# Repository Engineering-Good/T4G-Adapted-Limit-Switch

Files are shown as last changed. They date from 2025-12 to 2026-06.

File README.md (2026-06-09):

# Adapted Limit Switch
<!--- TITLE --->
<!--- Open Source Assistive Technology: GitHub Readme Template --->
<!--- SUMMARY --->
The Adapted Limit Switch is a cost effective, open source assistive switch similar to commercially available Wobble Switches. The switch is activated by applying force to and moving a wand in any direction. The switch can be activated by various body parts including the limbs and head. It provides a momentary closed contact that can be used to activate various assistive devices. The Adapted Limit Switch has an interchangeable topper that can be swapped for different shapes and sizes and the base can install with different type of camera mount or clamp . The switch requires approximately 0.55 N (55 gf) and about 24 mm of travel to operate, though this will vary a bit depending on the topper attached.

The current version of the device (v1.0) has been built and user tested.

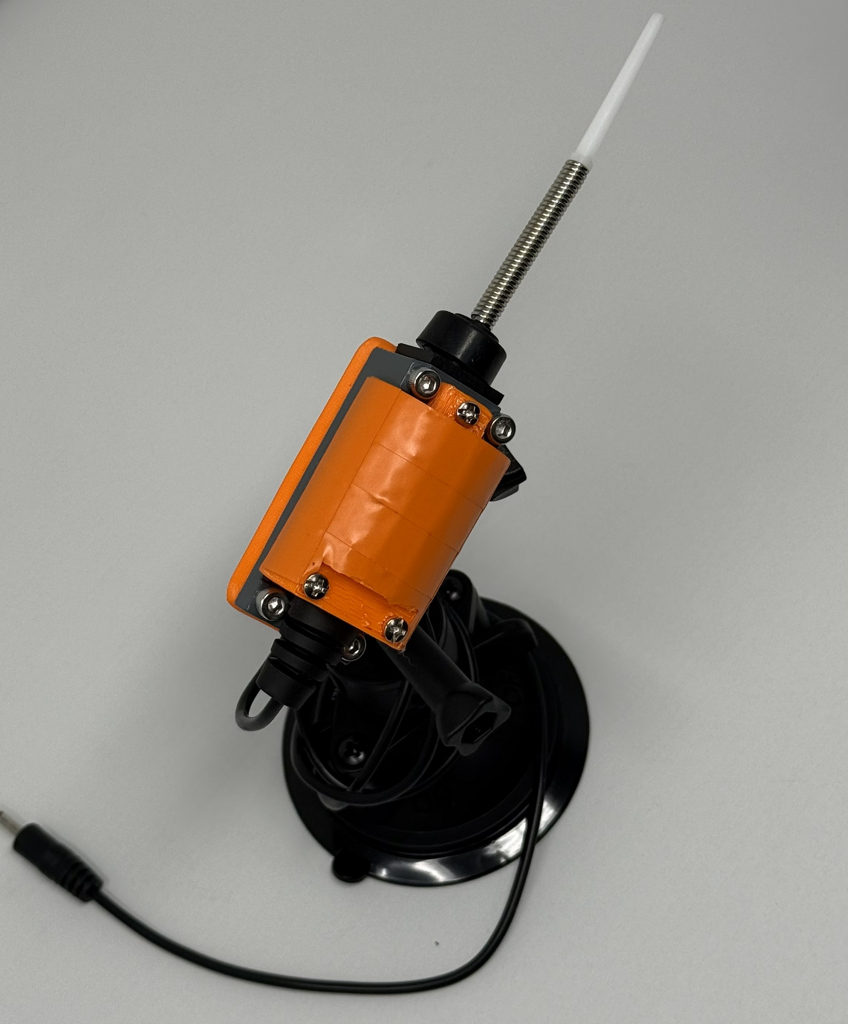
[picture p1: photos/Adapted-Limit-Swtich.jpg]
Picture of Adapted Limit Swtich


## How to Obtain the Device

### 1. Do-it-Yourself (DIY) or Do-it-Together (DIT)

This is an open-source assistive technology, so anyone is free to build it. All of the files and instructions required to build the device are contained within this repository. Refer to the Maker Guide below.

### 2. Get Involved: Requests & Volunteering

- Need this device? If you or someone you know could benefit from the Adapted Limit Switch, please send us an email at [contactus@engineeringgood.org](mailto:contactus@engineeringgood.org). We also invite you to share your journey with us! Tell us your stories about the device and feedback help us make our assistive tech even better!

- Want to help? We are always looking for volunteers to help build these devices for the community. If you have the skills and want to contribute, please contact us via email at [contactus@engineeringgood.org](mailto:contactus@engineeringgood.org).

## Build Instructions

### 1. Read through the Maker Guide

The [Maker Guide](/documentation/Product_Manual_Adapted_Limit_Switch.pdf)  contains all the necessary information to build this device, including tool lists, assembly instructions, and testing.

### 2. Order the Off-The-Shelf Components

The [Bill of Materials](/documentation/Adapted_Limit_Switch_BOM.csv) lists all of the parts and components required to build the Adapted Limit Switch.

### 3. Assemble the Adapted Limit Switch

Reference the Assembly Guide section of the [Maker Guide](/documentation/Product_Manual_Adapted_Limit_Switch.pdf) for the tools and steps required to build each portion.

## How to improve this Device

As open source assistive technology, you are welcomed and encouraged to improve upon the design.

## Files

### Documentation

| Document | Version | Link |
|---|---|---|
| Maker Guide | 1.0 | [Adapted_Limit_Switch_Maker_Guide](/documentation/Product_Manual_Adapted_Limit_Switch.pdf) |
| Bill of Materials | 1.0 | [Adapted_Limit_Switch_Bill_of_Materials](/documentation/Adapted_Limit_Switch_BOM.csv) |
| User Guide | 1.0 | [Adapted_Limit_Switch_User_Guide](/documentation/Product_Manual_Adapted_Limit_Switch.pdf) |
| Changelog | 1.0 | [Adapted_Limit_Switch_Change_Log](/documentation/CHANGES.txt) |

## Open Hardware Attribution

The core design for this Adapted Limit Switch is based on the Open Wobble Switch, an open-source assistive technology project.
- Original Designer: Makers Making Change (a program of Neil Squire).
- Original Copyright:  Copyright (c) Neil Squire / Makers Making Change.
- Original Source Location: The original project source files are available online at [Open Wobble Switch](https://www.makersmakingchange.com/product/open-wobble-switch/01tJR000000698oYAA0)

## License

Copyright (c) 2024 Engineering Good.

This repository describes Open Hardware:

- Everything needed or used to design, make, test, or prepare the Adapted Limit Switch is licensed under the [CERN 2.0 Weakly Reciprocal license (CERN-OHL-W v2) or later](https://cern.ch/cern-ohl).
- All software is under the [GNU General Public License v3.0 (GPL-3.0)](https://www.gnu.org/licenses/gpl.html).
- Accompanying material such as instruction manuals, videos, and other copyrightable works that are useful but not necessary to design, make, test, or prepare the Adapted Limit Switch are published under a [Creative Commons Attribution-ShareAlike 4.0 license (CC BY-SA 4.0)](https://creativecommons.org/licenses/by-sa/4.0/).

You may redistribute and modify this documentation and make products using it under the terms of the [CERN-OHL-W v2](https://cern.ch/cern-ohl).
This documentation is distributed WITHOUT ANY EXPRESS OR IMPLIED WARRANTY, INCLUDING OF MERCHANTABILITY, SATISFACTORY QUALITY AND FITNESS FOR A PARTICULAR PURPOSE.
Please see the CERN-OHL-W v2 for applicable conditions.

Source Location: <https://github.com/makersmakingchange/Open-Wobble-Switch>

----

<!-- ABOUT EG START -->
## About Engineering Good

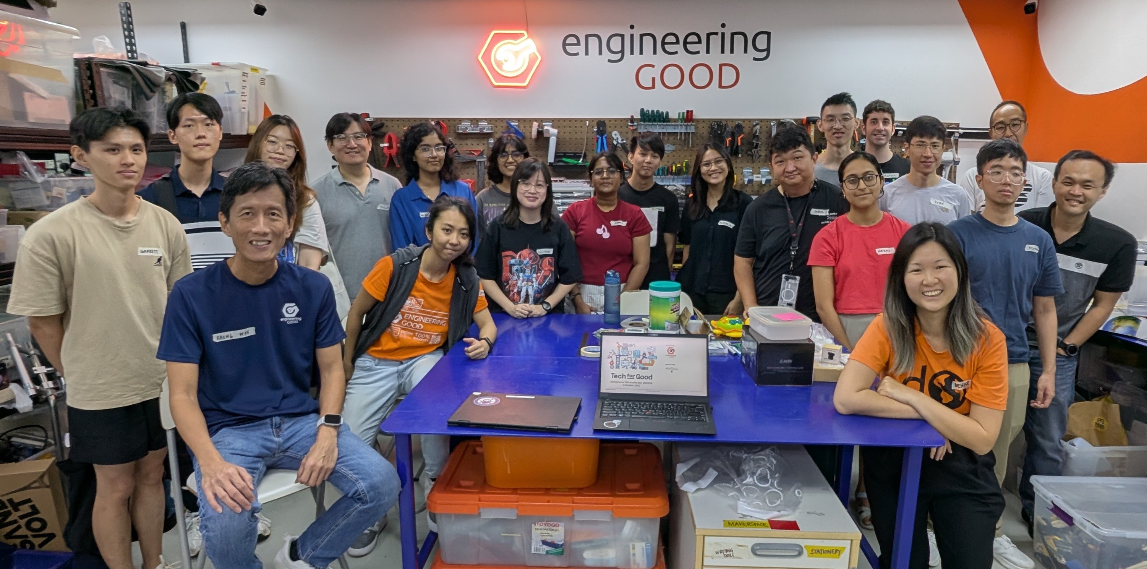
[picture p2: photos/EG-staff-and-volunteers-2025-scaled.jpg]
Picture of EG staff and volunteers.


- Website: [https://www.engineeringgood.org](https://www.engineeringgood.org)
- GitHub: [Engineering Good](https://github.com/Engineering-Good)
- Instagram: [@engineeringgood](https://www.instagram.com/engineeringgood/)
- Facebook: [engineeringgood](https://www.facebook.com/engineeringgood.org/)
- LinkedIn: [engineeringgood](https://www.linkedin.com/company/engineeringgood/?originalSubdomain=sg)
- Thingiverse: [engineeringgood](https://www.thingiverse.com/engineeringgood/designs)
- Printables: [@engineeringg_4351657](https://www.printables.com/@engineeringg_4351657)

### Contact Us

For technical or non-techical questions, to get involved, or to share your experience we encourage you to 
- Visit [our website](https://www.engineeringgood.org/)
- Vontact us via [contact us form](https://www.engineeringgood.org/contact-faq/)
- Email us at [contactus@engineeringgood.org](mailto:contactus@engineeringgood.org)
- Volunteering Opportunities [working in progress](https://www.notion.so/engineeringgood/Volunteering-Opportunities-2025-ffa3d3ec8bb34ac7a672f5c10ee8177b)
<!-- ABOUT EG END -->

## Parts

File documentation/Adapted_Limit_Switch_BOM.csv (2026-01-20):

Item | Product Link | Supplier | Price | Quantity
3D printed top part | https://www.polymate.tech/3d-printing-orders | Polymate | 3.00 SGD/pcs | 1
3D printed bottom part | https://www.polymate.tech/3d-printing-orders | Polymate | 3.00 SGD/pcs | 1
Limit switch | https://amzn.asia/d/4A6GOT8 | Amazon | 22.08 SGD | 1
3.5mm male mono audio jack cable | https://sg.shp.ee/Wysp8yu | Shopee | 5.42 SGD/10pcs | 1
M3 x 20mm partially threaded screw | https://sg.shp.ee/Db9QmNu | Shopee | 6.16 SGD/3pcs | 2
M3 x 6mm screw | https://sg.shp.ee/EN4TQR4 | Shopee | 1.80 SGD/pcs | 1
M4 x 16mm bolt | https://sg.shp.ee/2jGwF62 | Shopee | 1.67 SGD/5pcs | 2
M4 x 30mm bolt | https://sg.shp.ee/zS49WkP | Shopee | 1.90 SGD/5pcs | 2
M4 nut | https://sg.shp.ee/pazvoqT | Shopee | 1.87 SGD/20pcs | 4
M5 Tee nut 1/4"-20 | https://amzn.asia/d/fEdIprT | Amazon | 24.50 SGD/100pcs | 1
Bicycle soft handle grip | https://shop.daisosingapore.com.sg/products/4550480051574 | Daiso | 2.18 SGD/2pcs | 1
Soft ball | https://sg.shp.ee/dVmJJah | Shopee | 0.73 SGD/pcs | 1

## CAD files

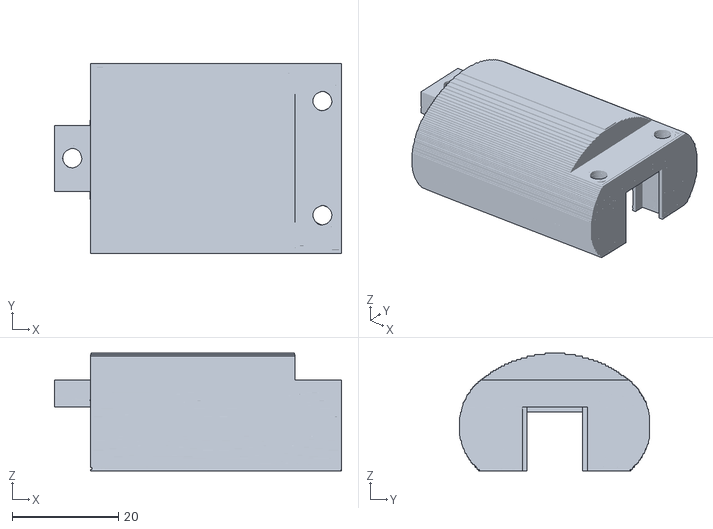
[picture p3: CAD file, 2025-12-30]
design-files/cad-files/Top_Piece.stl
54.1 x 35.9 x 22.2

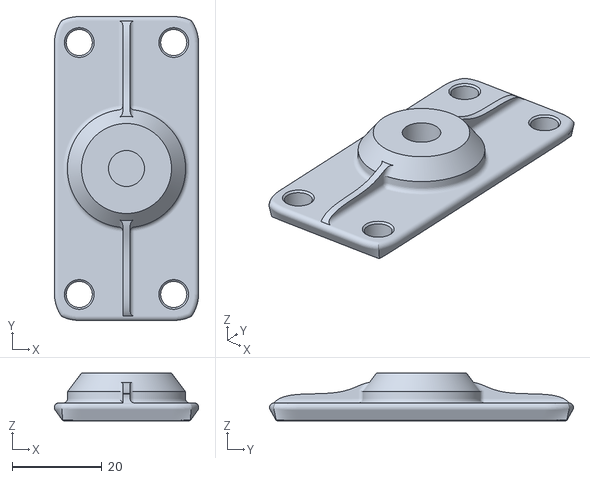
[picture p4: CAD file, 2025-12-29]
design-files/cad-files/Bottom_Piece.stl
32.1 x 67.6 x 10.7

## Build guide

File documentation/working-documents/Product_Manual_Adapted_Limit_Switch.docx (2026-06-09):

# Product Manual: Adapted Limit Switch

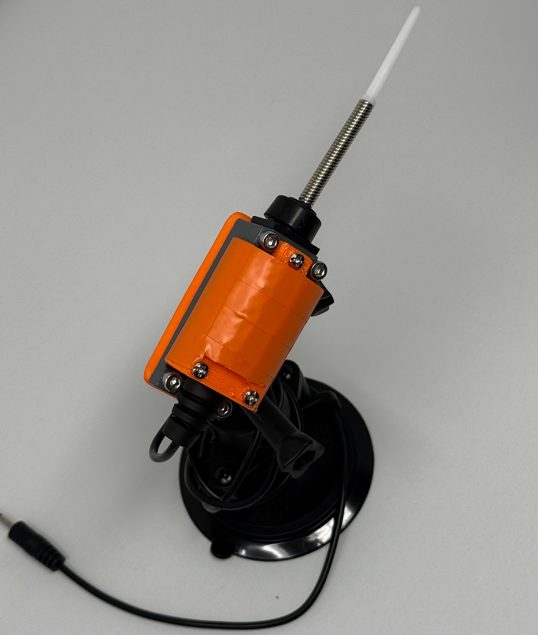
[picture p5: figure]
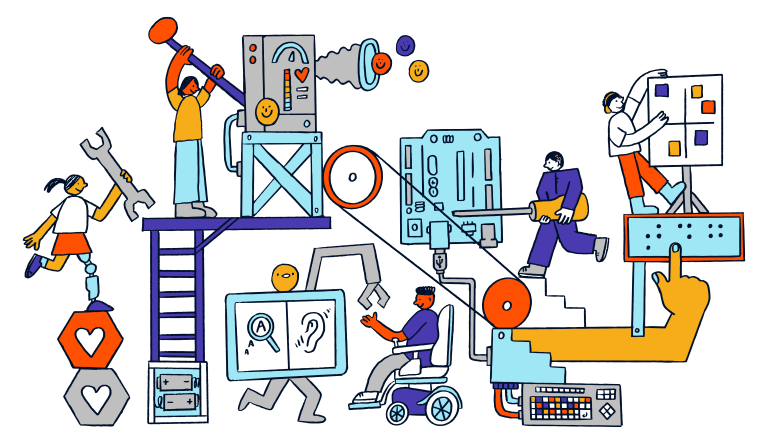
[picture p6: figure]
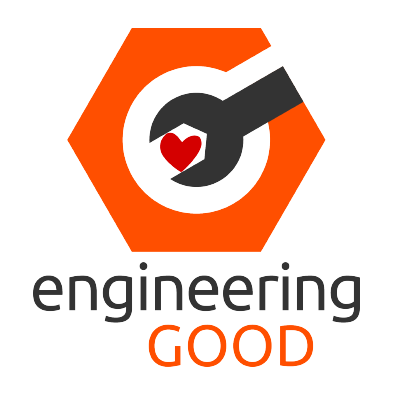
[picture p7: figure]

Revision: 1.0

Date: 03-Dec-2025

# Table of Contents

Table of Contents 1

1. Introduction 2

1.1 About the Community Partner 2

1.2 Product Description 3

WHY? 3

WHO? 3

WHAT? 3

HOW? 3

1.3 Product Overview and Features 4

1.4 Bill of Materials (BOM) 5

2. User Guide: Instructions for Use 6

2.1 Set Up Instructions 7

2.2 Maintenance 10

2.3 Troubleshooting 10

3. Maker Guide: Assembly Instructions 11

3.1 Assembly Guide 12

4. Credit and Open Hardware Licence 15

4.1. Open Hardware Attribution 15

4.2. License Statement and Source Availability 16

4.3 CERN Open Hardware Licence 16

# 1. Introduction

## 1.1 About the Community Partner

Our journey began in 1970 with the will of Mrs Shakuntala Bhatia. Under the banner of the Asian Women’s Welfare Association, Mrs Bhatia and her peers, like Mrs Tambyah and Mrs Kula, identified gaps in the community to help the underserved.

The Association incorporated AWWA Ltd on 7 January 2015, a Singapore company limited by guarantee. In April of the same year, AWWA Ltd took over the operations and activities previously managed by the Association. In 2022, the Association was dissolved, and AWWA continues to address social service gaps as they arise, by being guided by our mission and strategic vision.

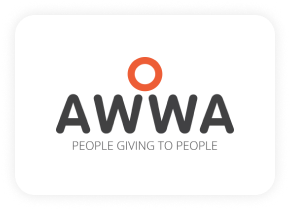
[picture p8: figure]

## 1.2 Product Description

This table clarifies the intended purpose and scope of the product:

WHY? | Special needs students with low mobility are often excluded from using toys and/or face lack of appropriate ways to express themselves.
WHO? | For special needs students with low mobility who are learning to understand cause-and-effect and have fun.
WHAT? | A limit switch with an additional 3.5mm male mono audio cable to trigger the power of other toys or play back audio. 3D printed casing with camera mounting hole for easy install clamp and mount on the wheelchair
HOW? | This product transforms an off-the-shelf limit switch into a durable and responsive device that triggers power on/off other toys or playback audio and an easy mounting mechanism . It allows students to use the limit switches to experience and understand the cause-and-effect.

## 1.3 Product Overview and Features

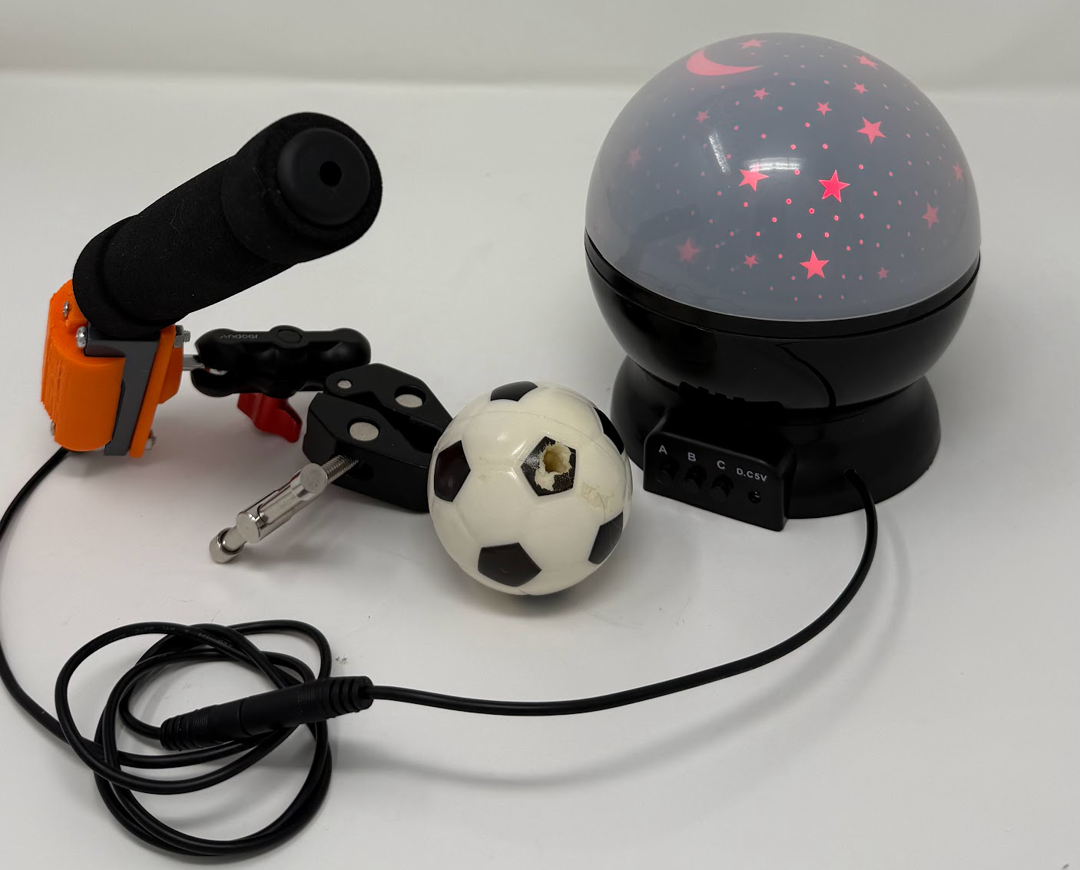
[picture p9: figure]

1. Adapted Limit Switch support push in all directions to trigger. Left, right, up or down it can be triggered.
2. Add-on soft ball, soft bicycle handle or soft toy to trigger stick to make it more interesting to students to try it out.
3. Can support different types of mounting or clamp system with standardised camera mount.
4. Connect to other electronic toys with a female 3.5mm mono audio jack cable.

## 1.4 Bill of Materials (BOM)

Item | Product Link | Supplier | Price | Quantity
3D printed top part | https://www.polymate.tech/3d-printing-orders | Polymate | 3.00 SGD/pcs | 1
3D printed bottom part | https://www.polymate.tech/3d-printing-orders | Polymate | 3.00 SGD/pcs | 1
Limit switch | https://amzn.asia/d/4A6GOT8 | Amazon | 22.08 SGD | 1
3.5mm male mono audio jack cable | https://sg.shp.ee/Wysp8yu | Shopee | 5.42 SGD/10pcs | 1
M3 x 20mm partially threaded screw | https://sg.shp.ee/Db9QmNu | Shopee | 6.16 SGD/3pcs | 2
M3 x 6mm screw | https://sg.shp.ee/EN4TQR4 | Shopee | 1.80 SGD/pcs | 1
M4 x 16mm bolt | https://sg.shp.ee/2jGwF62 | Shopee | 1.67 SGD/5pcs | 2
M4 x 30mm bolt | https://sg.shp.ee/zS49WkP | Shopee | 1.90 SGD/5pcs | 2
M4 nut | https://sg.shp.ee/pazvoqT | Shopee | 1.87 SGD/20pcs | 4
M5 Tee nut 1/4"-20 | https://amzn.asia/d/fEdIprT | Amazon | 24.50 SGD/100pcs | 1
Bicycle soft handle grip | https://shop.daisosingapore.com.sg/products/4550480051574 | Daiso | 2.18 SGD/2pcs | 1
Soft ball | https://sg.shp.ee/dVmJJah | Shopee | 0.73 SGD/pcs | 1

# 2. User Guide: Instructions for Use

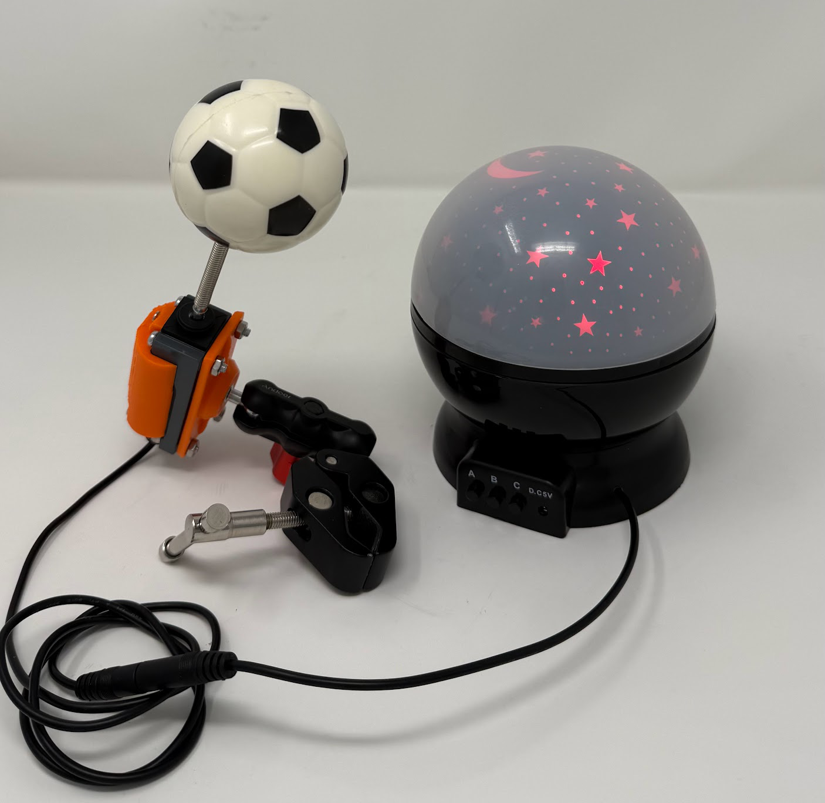
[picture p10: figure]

## 2.1 Set Up Instructions

Use the following table for a step-by-step guide to setting up the product:

Setting up

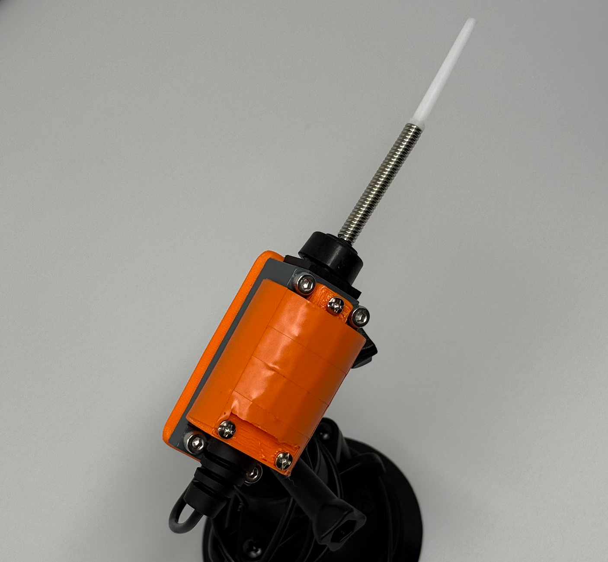
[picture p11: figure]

Push the white or spring to the left or right to trigger it.

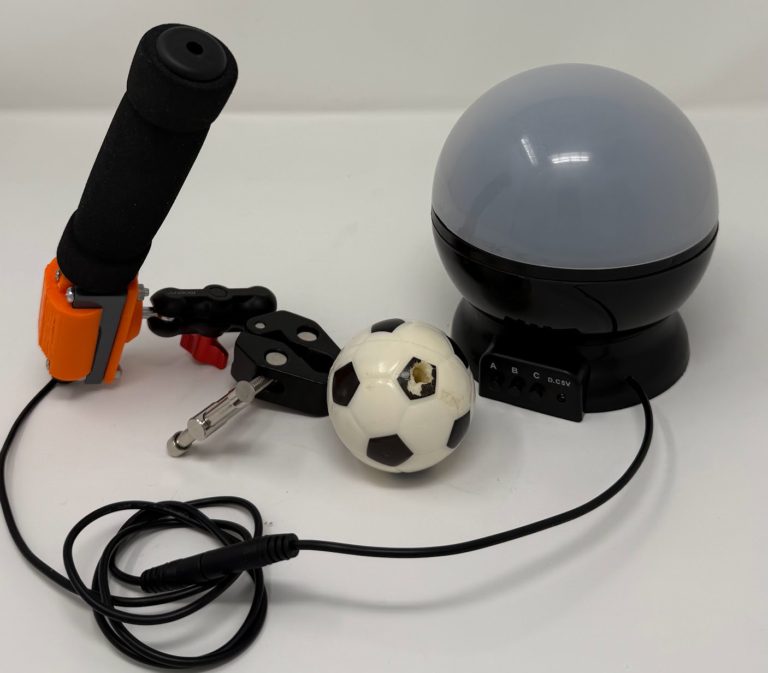
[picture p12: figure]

Connect the 3.5mm male mono audio jack cable to toys

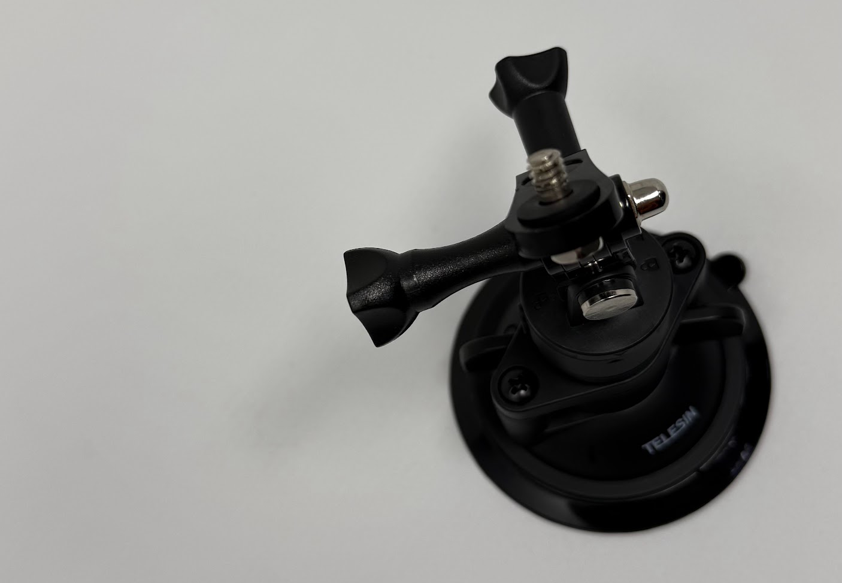
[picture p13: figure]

Suction cup mount. Secure the device properly by pushing the locking lever at the bottom side of the mount. It should be used on a flat surface.

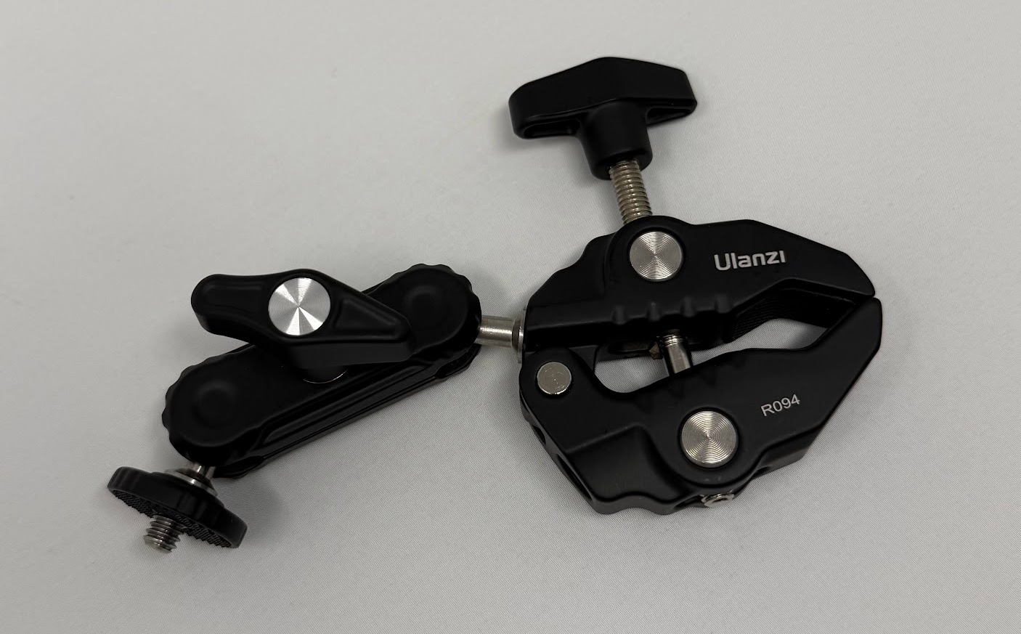
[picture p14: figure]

Clamp mount. Secure the device properly by turning the big knob and change the angle with the small knob on the mount. It is mostly used on a wheelchair.

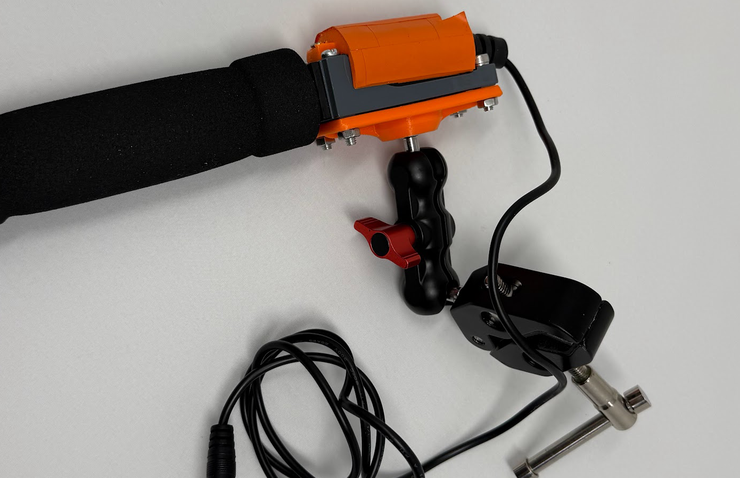
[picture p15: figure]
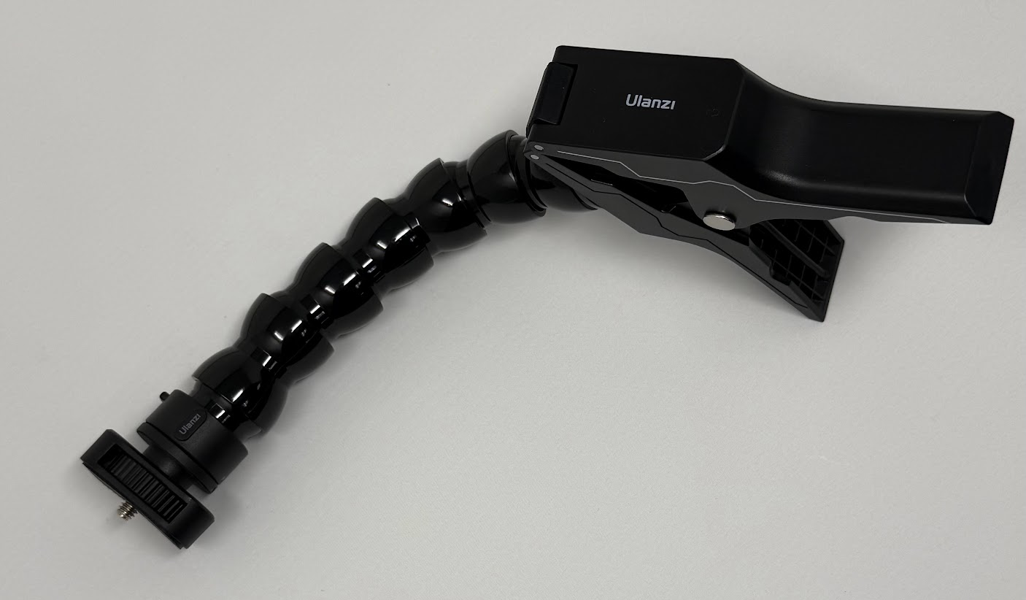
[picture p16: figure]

Gooseneck mount. Secure the device properly by squeezing the clip part and the gooseneck can adjust the angle. It is mostly used on a wheelchair.

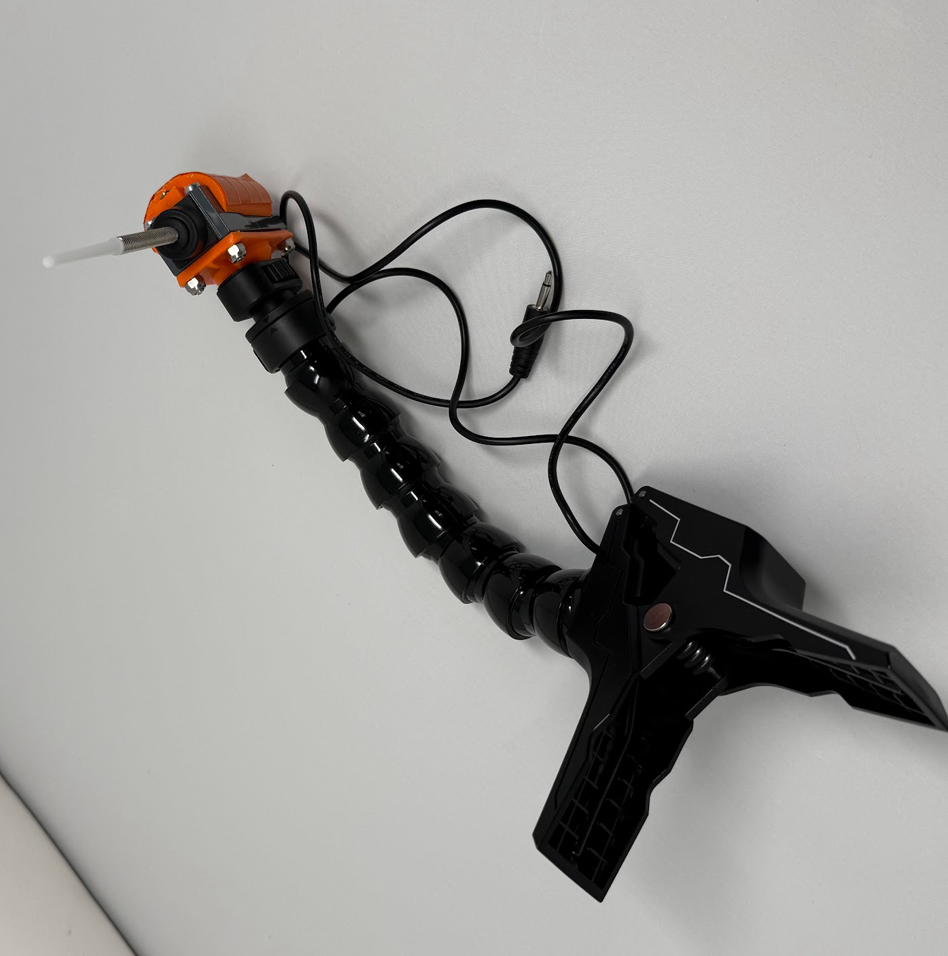
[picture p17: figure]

## 2.2 Maintenance

1. Check the clamp mounting if it is loose.
2. Check the 3.5mm male mono audio jack cable if it is loose or damaged.

## 2.3 Troubleshooting

Problem | Possible Cause | What You Can Try
The clamp or mount is loose so didn’t trigger toy | Didn’t clamp or mount properly | Read user guide on how those clamp and mount works
Not triggering the toy even is mounted properly | Toy issues | Check on the Toy product manual
| Limit switch connection broken | Open with the assembly instruction and try to check on it or contact EG for support.

# 3. Maker Guide: Assembly Instructions

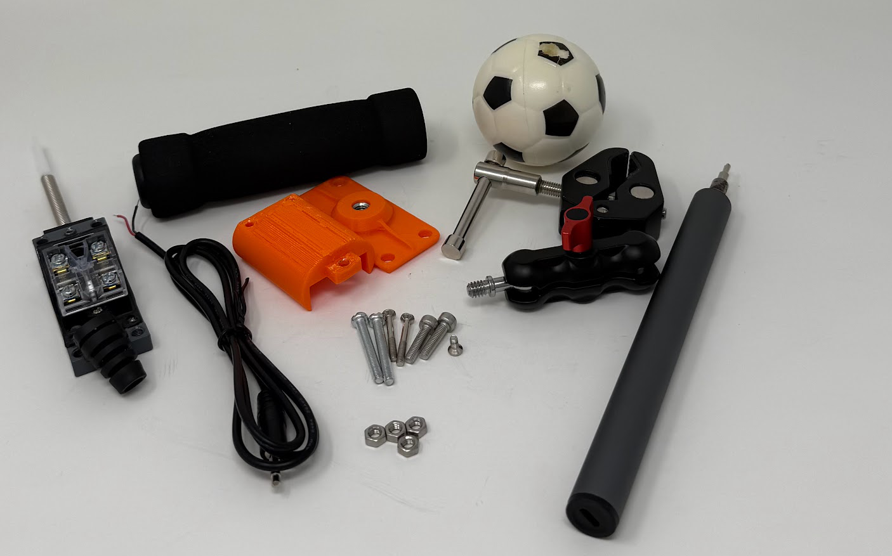
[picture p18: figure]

## 3.1 Assembly Guide

Steps | Images

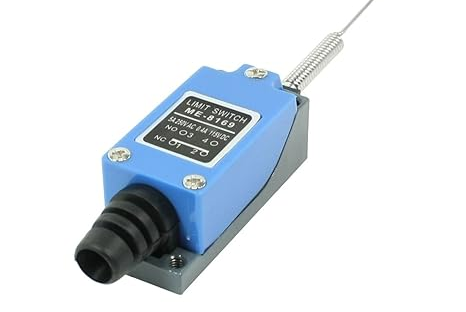
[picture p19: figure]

Remove all the 3 screws from the limit switch.

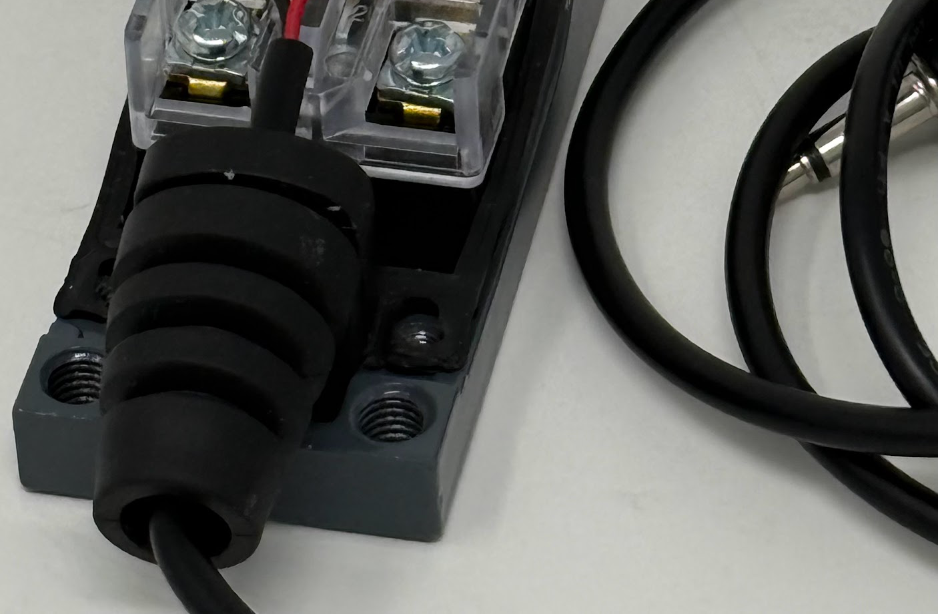
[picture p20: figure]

Put the 3.5mm male mono audio jack cable through the flexible strain relief.

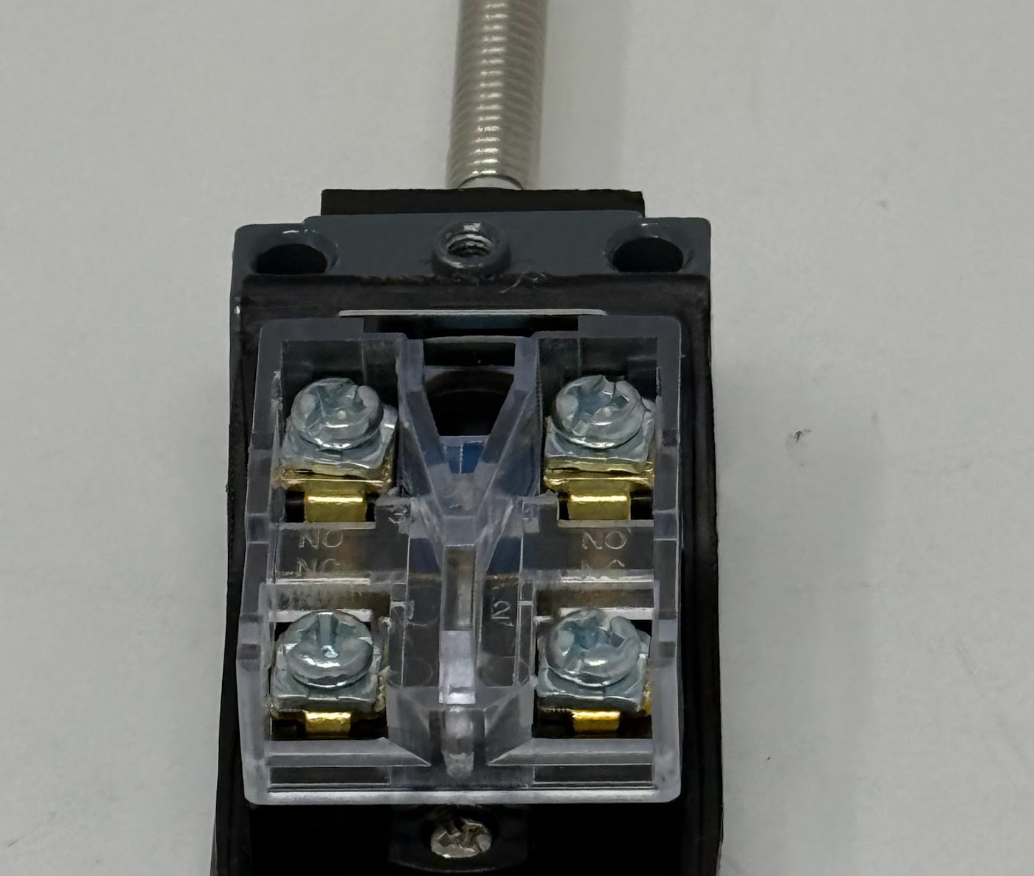
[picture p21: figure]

Unscrew the top 2 “NO” screws until the wire from the 3.5mm male mono audio jack wire can go through it.

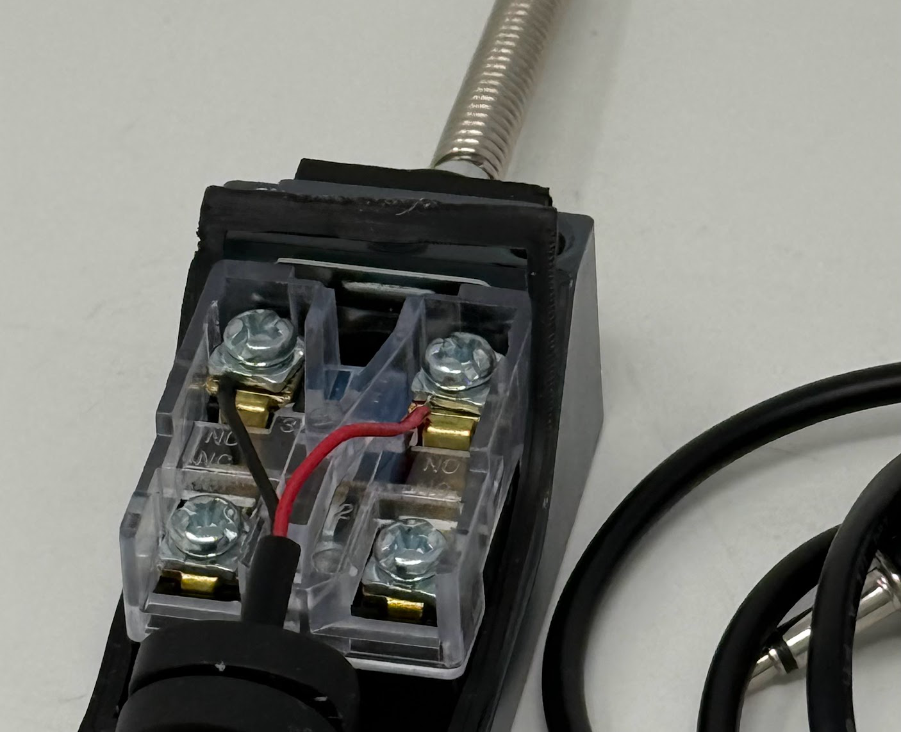
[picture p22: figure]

Screw back the top 2 “NO”.

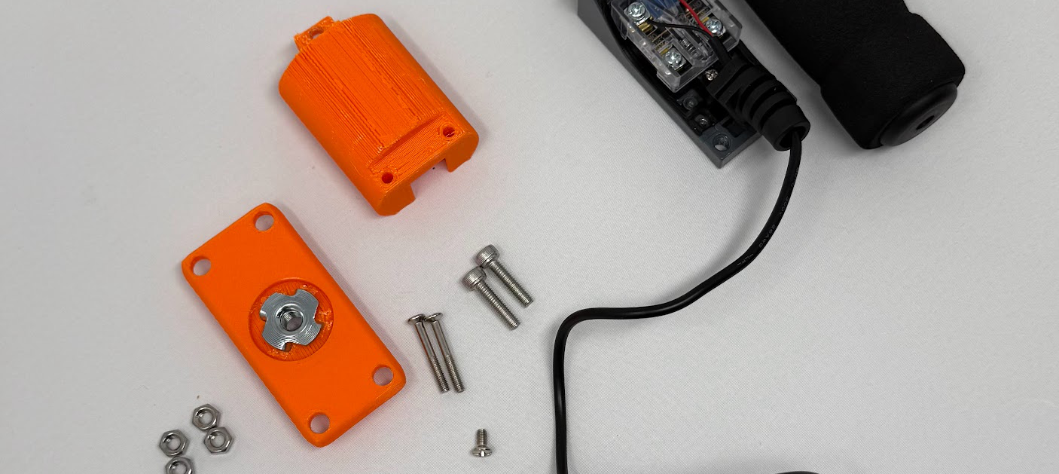
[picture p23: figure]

With the 3D printed bottom part and insert the tee nut into the hole on the flat side and use a M5 bolt to screw so the tee nut will bite into the 3D printed part.

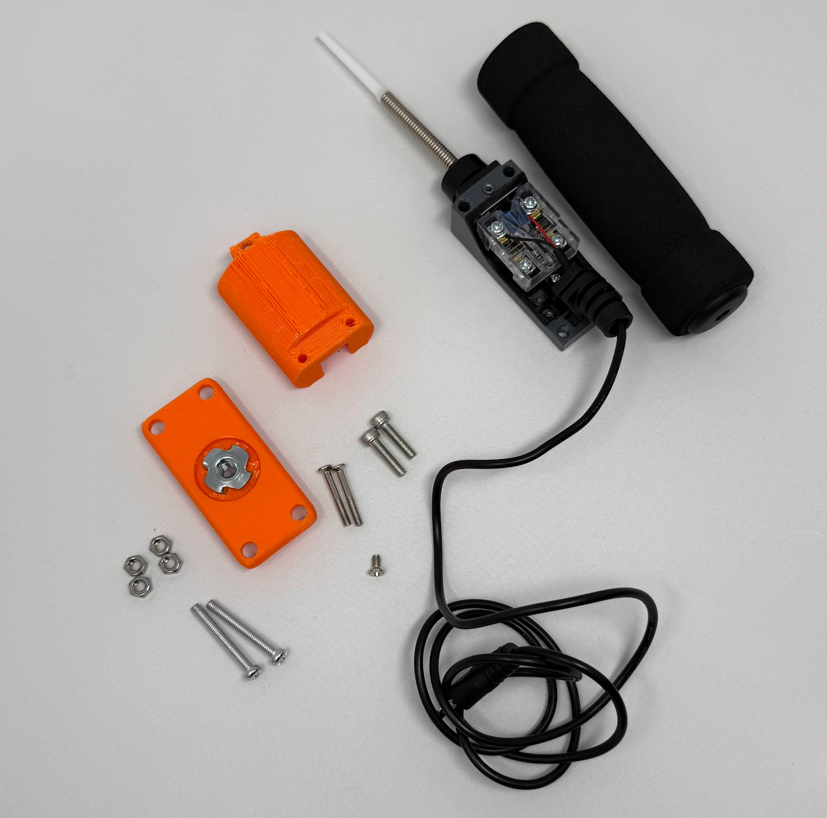
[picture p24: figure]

With the 3D printer top and cover up the limit switch and screw the 3 screw and 4 bolt/nuts.

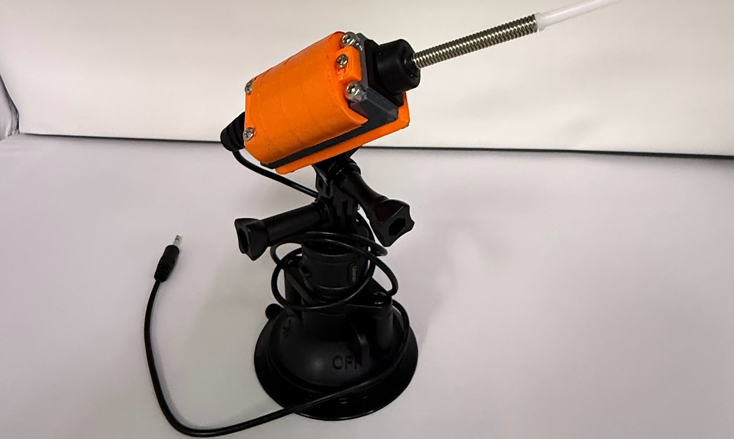
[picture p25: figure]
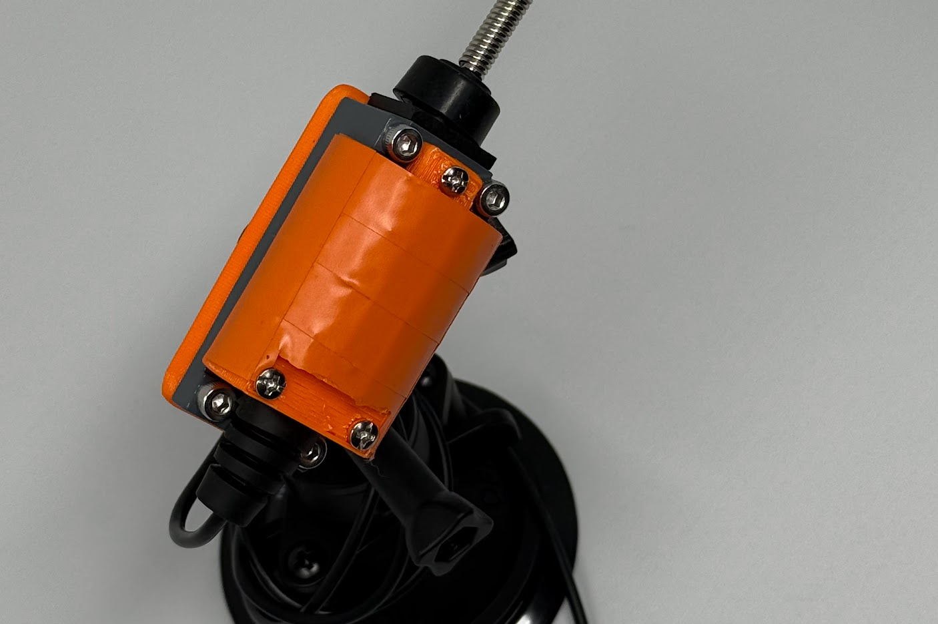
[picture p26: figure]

Screw the different mount or clamp into the bottom tee nut.

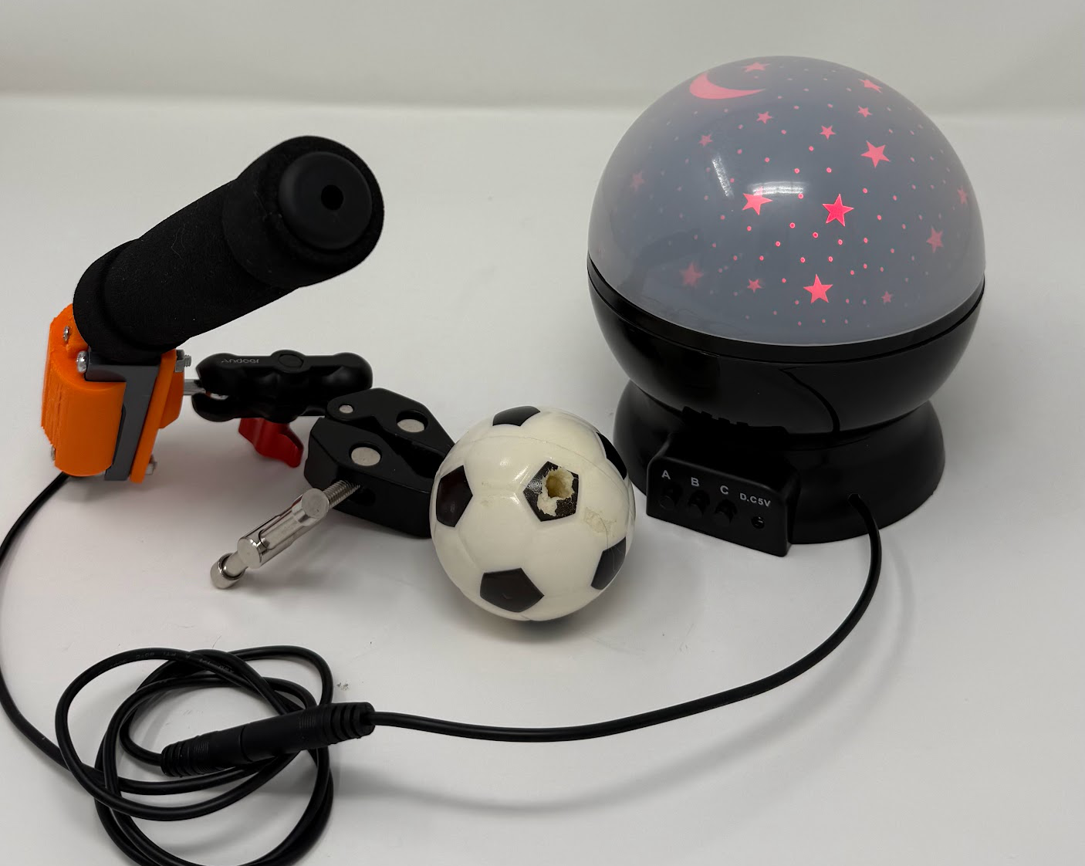
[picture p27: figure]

Test with a toy to see if it works.

# 4. Credit and Open Hardware Licence

This section provides the required legal notices and attribution for the open hardware design used to create this product.

## 4.1. Open Hardware Attribution

The core design for this Adapted Limit Switch is based on the Open Wobble Switch, an open-source assistive technology project.

- Original Designer: Makers Making Change (a program of Neil Squire).
- Original Copyright: Copyright (c) Neil Squire / Makers Making Change.
- Original Source Location: The original project source files are available online at: https://www.makersmakingchange.com/product/open-wobble-switch/01tJR000000698oYAA

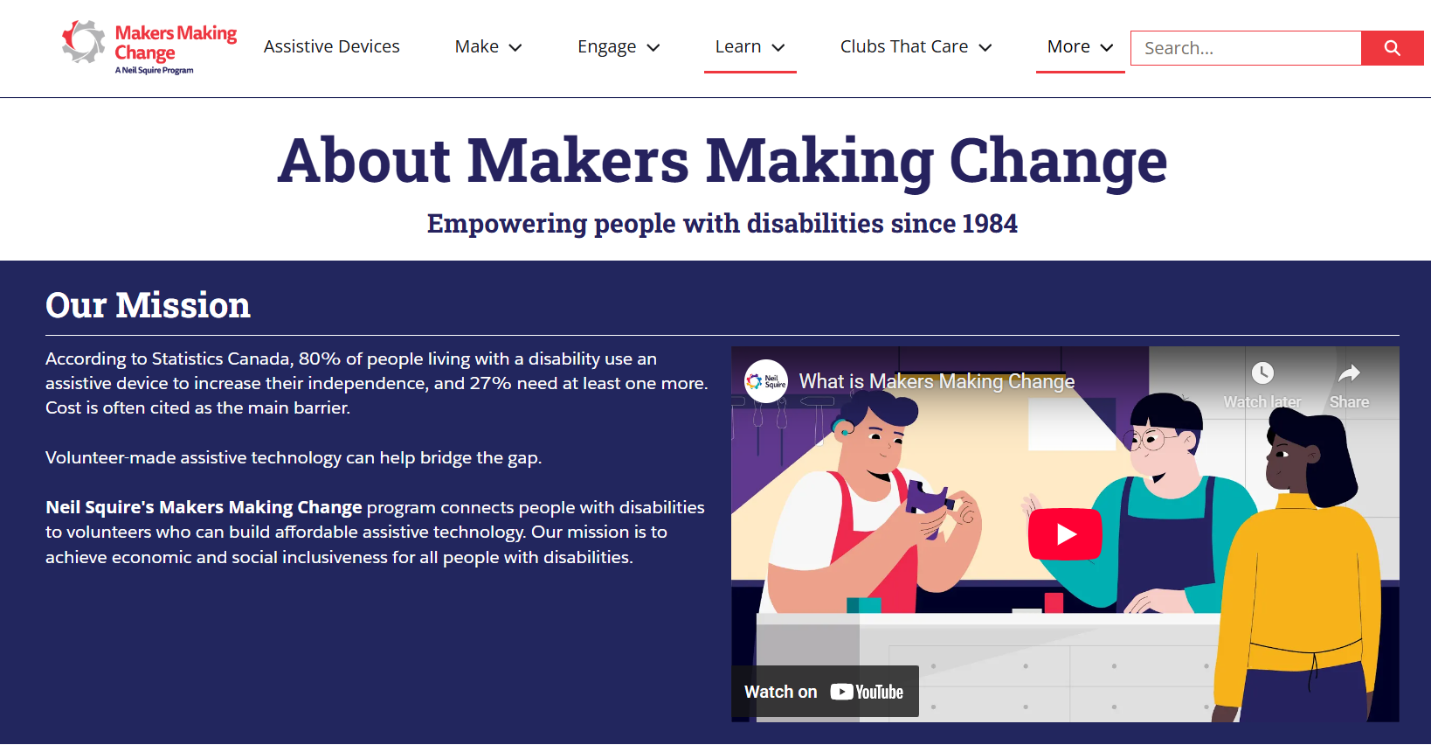
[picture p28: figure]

## 4.2. License Statement and Source Availability

The hardware design used in this product is licensed under the CERN Open Hardware Licence Version 2 – Weakly Reciprocal (CERN-OHL-W 2.0) or later.

By distributing this product, we are obligated to make the complete design source available to you.

- Complete Source Availability: The complete design files (Source), including schematics, assembly instructions, and any modifications made by Engineering Good, are available free of charge at a permanent online location: https://github.com/Engineering-Good/T4G-Adapted-Limit-Switch
- Modification Notice: This version of the Adapted Limit Switch design was modified by Engineering Good to include the 3.5mm mono audio jack functionality for triggering other toys. The full, modified source is available at the URL listed above.
- Full License Text: The complete legal text of the CERN Open Hardware Licence Version 2 – Weakly Reciprocal** follows this section.

## 4.3 CERN Open Hardware Licence

The full text of the license is available here: (https://gitlab.com/ohwr/project/cernohl/-/wikis/uploads/82b567f43ce515395f7ddbfbad7a8806/cern_ohl_w_v2.txt)CERN-OHL-W 2.0 Full Text (https://gitlab.com/ohwr/project/cernohl/-/wikis/uploads/82b567f43ce515395f7ddbfbad7a8806/cern_ohl_w_v2.txt)

https://www.engineeringgood.org/bespoke-projects/ © 2024 Engineering Good

2025/2026 Adapted Limit Switch Product Handbook Rev: 1.0

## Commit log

2025-12-29 add bttom stl file to cad folder
    [OWS_Mounting_Adapter.stl]
2025-12-29 License part using template or playback switch name
2025-12-29 Fixed all the typo from Adapted Recorded Button to Adapted Limit Switch
2025-12-30 update documentation with 3d print part pricing. Added the STL and Gcode files to cad folder.
    [Bottom_Piece.stl, Top_Piece.stl]
2026-01-20 update readme and BOM.
    [Adapted_Limit_Switch_BOM.csv]
2026-04-16 update documenation BOM with short url and new group photo.
2026-04-16 fix Thingiverse and Printables to readme file
    (cherry picked from commit b876ce58b2a5f3f7fe9be916a5b8981694906ba0)
